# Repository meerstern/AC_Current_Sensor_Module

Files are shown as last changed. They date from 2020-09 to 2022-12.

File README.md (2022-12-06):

# AC電流センサ基板
Minimally invasive current sensor board

## 概要 
  * ホール素子を用いた商用交流用の電流センサ基板です  
  * 一般的なCT電流センサでは片方のみをクランプさせる必要があり、電源ケーブルの加工が必要です  
  * 一方、当センサは一般的な電源ケーブルを加工せずにそのまま近接させて使用します  
  * 機器のON、OFF状態の確認や大まかな電流変化の確認用途に最適です  
  * 電源ケーブルに近接させるだけで、電源ケーブルの電流に比例したアナログ電圧が出力されます  
  * 可変抵抗RV1で感度調整が可能です  
  * センサ電源は2.5V～5V電源を供給してください  
  
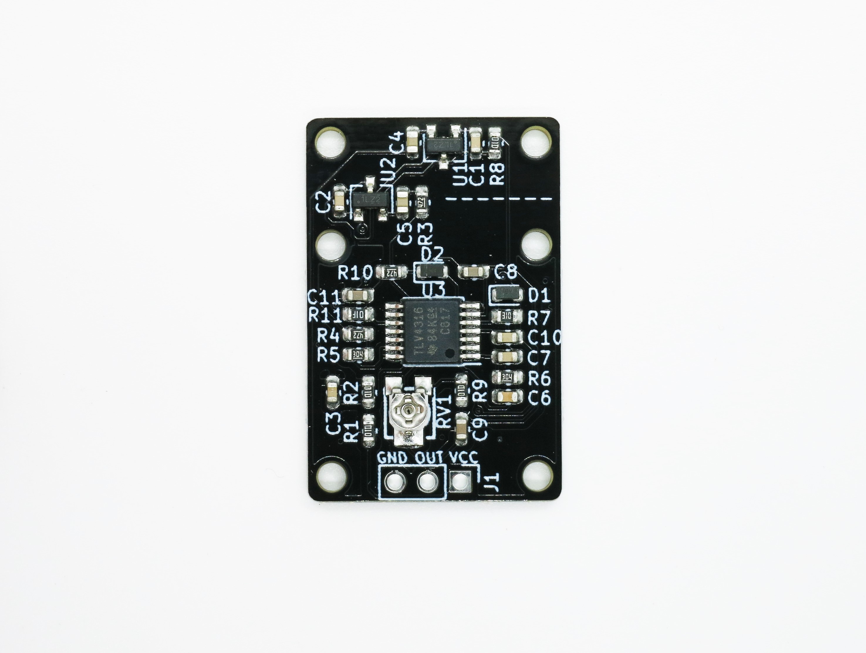
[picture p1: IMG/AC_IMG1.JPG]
   
   
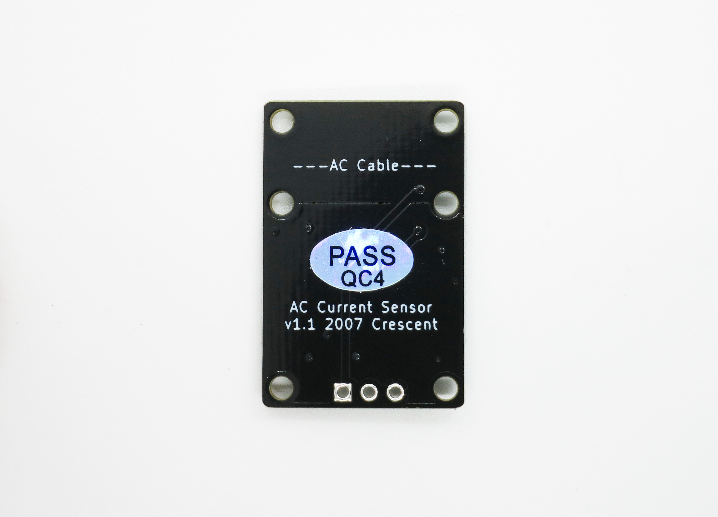
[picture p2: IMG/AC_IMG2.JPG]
   

## 使用方法
　* 小電流(数10W～数100W程度)の場合は部品側にシルクの点線に合わせて電源ケーブルを固定してください  
 
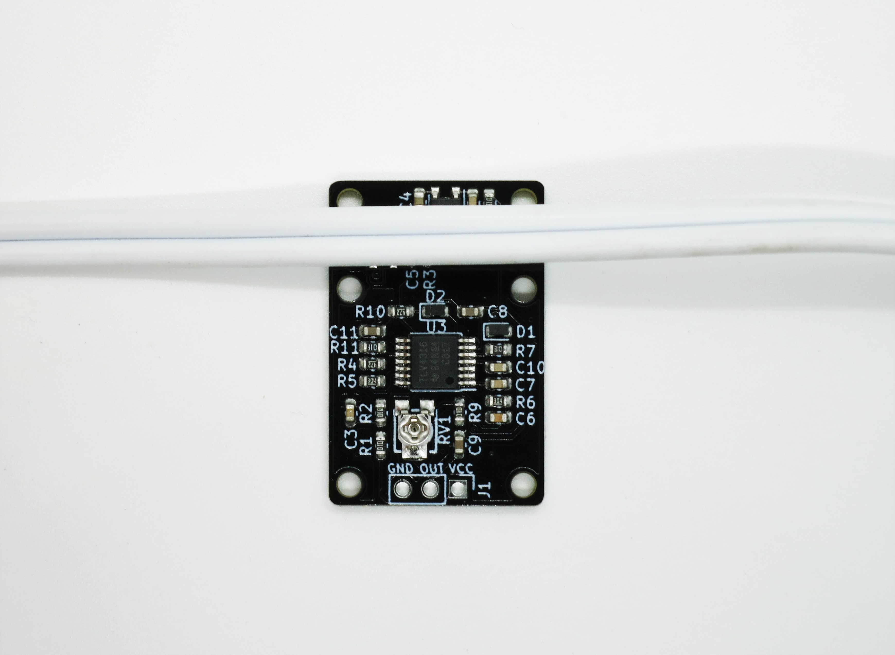
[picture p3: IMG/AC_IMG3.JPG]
 
　
  * 大電流(数100W～1000W程度)の場合は部品裏側のシルク点線に合わせて電源ケーブルを固定してください  
  
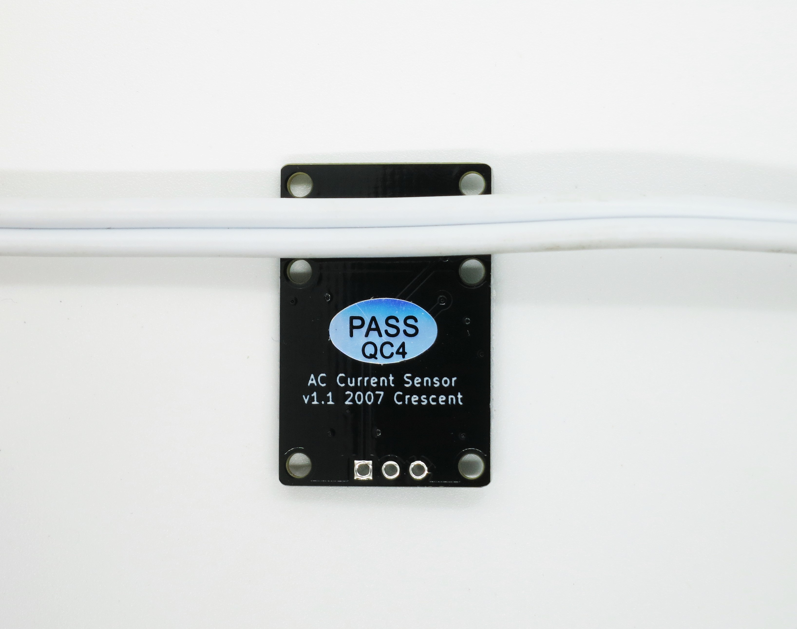
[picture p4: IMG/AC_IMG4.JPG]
 
 
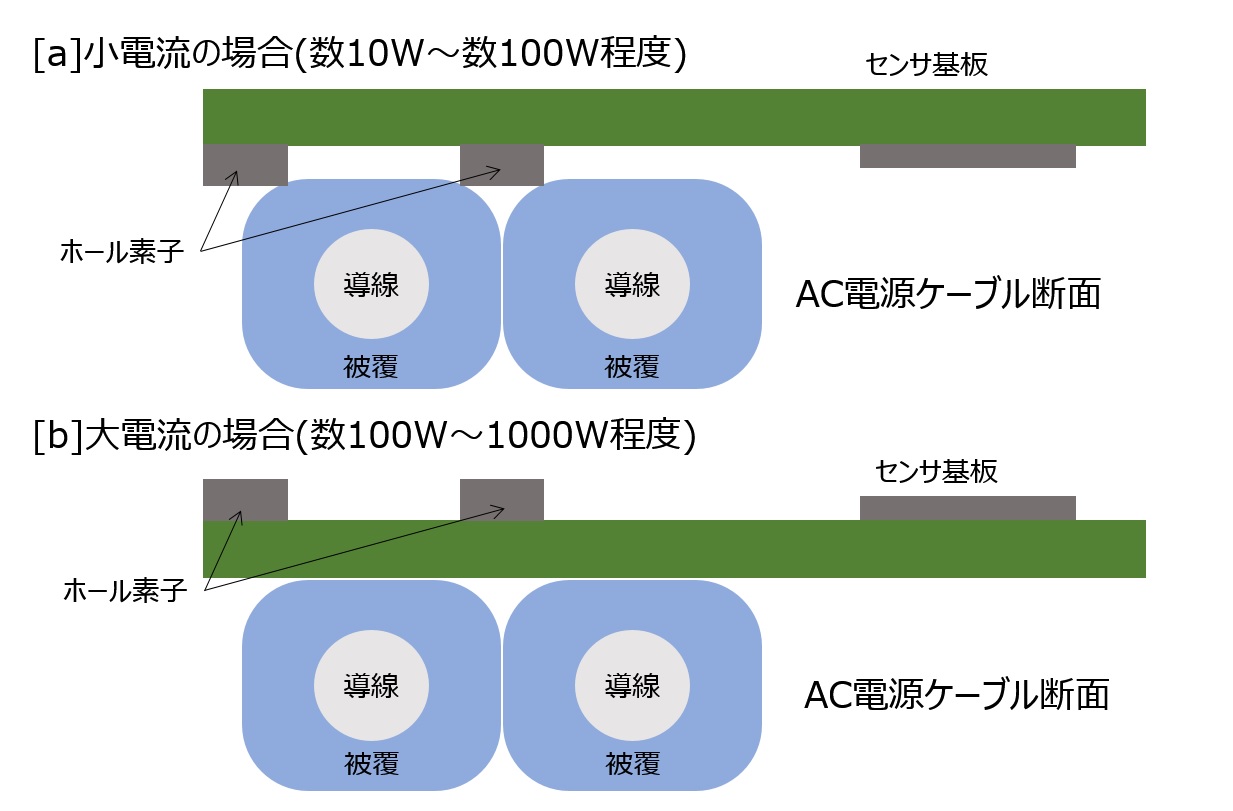
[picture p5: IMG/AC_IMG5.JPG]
 
 
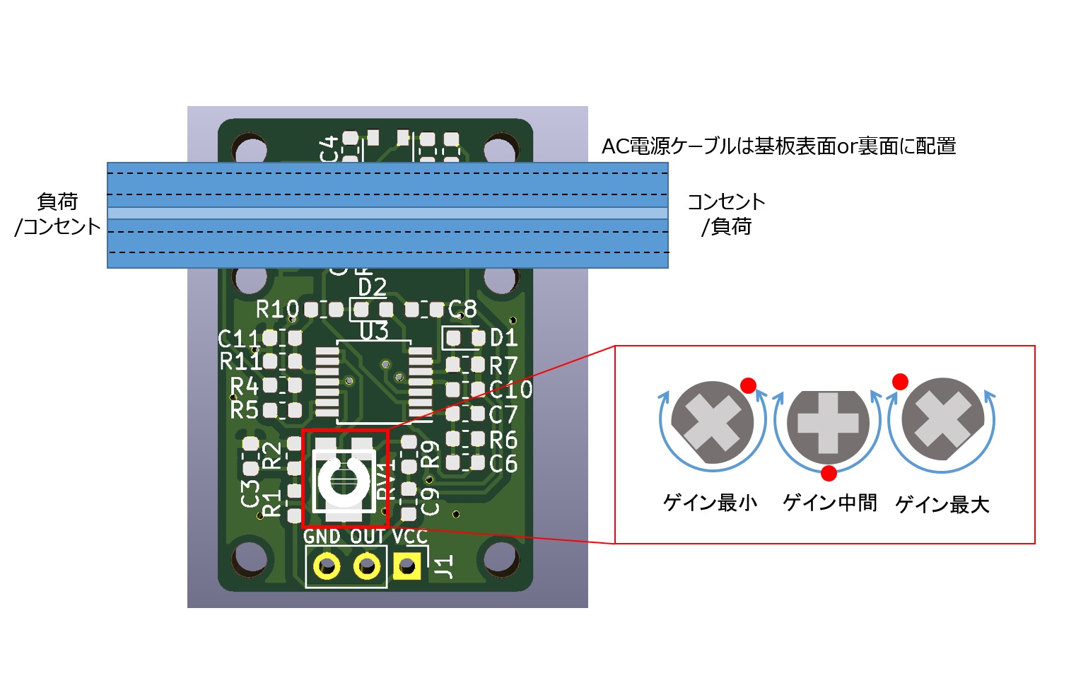
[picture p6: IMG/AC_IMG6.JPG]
 
 
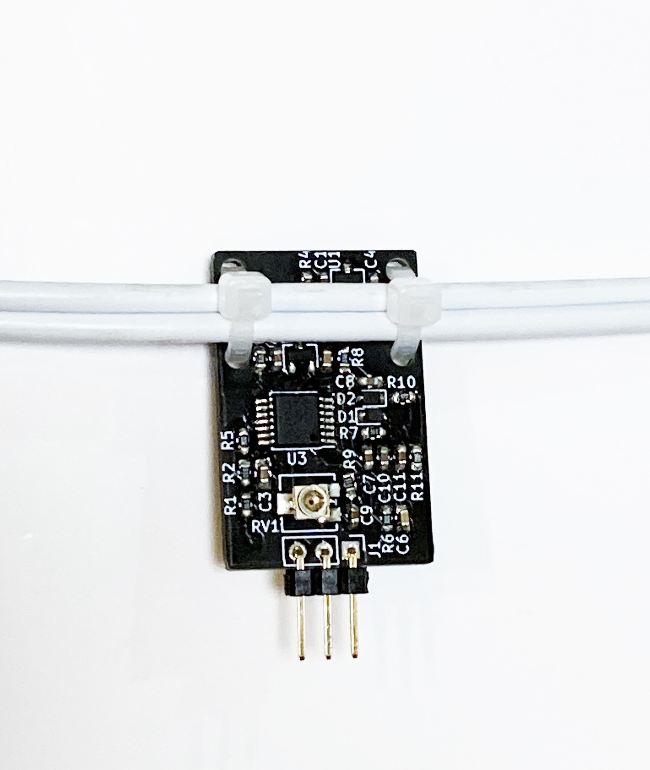
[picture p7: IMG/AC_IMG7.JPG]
 
    
## 注意 
 * 布巻き電源ケーブルや傷、破損のある電源ケーブルに対して使用しないでください  
 * 電源ケーブルの破損防止のため、電源ケーブルとセンサ基板を強く固定しないでください  
 * 当電流センサ基板は商用交流(50Hz、60Hz)専用で直流電流やその他交流電流の測定には使用できません  
 * 実験、評価用途を目的としています  
 * 15A以上の電流測定には使用しないでください  
 * 商用電源のノイズがアナログ出力に入る場合は必要に応じて、フィルタ処理をしてください  
 * 磁界変化をピークホールドさせるため、急激な電流変化や微小な電流変化の検出はできません  
 * 同じ電流であっても電源ケーブルの種類や取り付け位置によっても磁界の大きさが変化し、出力も合わせて変化します  
 * 電流とアナログ出力電圧の関係は事前にクランプ式電流センサ等で確認してください  
 * 負荷や使用する電源ケーブルによっては電流に対してアナログ出力が１次比例しない場合があります  
 * 電源ケーブルと電流センサ基板の取り付け位置を固定させて使用してください  
 * 当電流センサ基板上の部品を手で触れた状態では出力が不安定化する場合があります  
 * 可変抵抗RV1で感度によって異なりますが、電流0であってもオフセット電圧が0.2V~2V程度出力されます  
 * 当センサを使用したことによって発生した、いかなる損害については責任を負いかねます  
 
 ## 改版情報
 * v1.1→v1.2で出力リップル及び出力オフセット低減のため、変更しています(R9:100k→0ohm、C6:2nF→10nF)  
 * 基板レイアウトを一部変更していますが、回路に変更はありません  
 
 ## 販売サイト
  * [スイッチサイエンス][2]
  
  [2]: https://www.switch-science.com/products/6582
 
 MIT Lisense

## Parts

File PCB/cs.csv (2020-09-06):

ID | 参照記号 | パッケージ | 数 | 名称 | Supplier and ref
1 | REF4,REF6,REF5,REF3,REF4,REF1,REF2 | MountingHole_2.2mm_M2 | 7 | MountingHole_2.2mm_M2
2 | RV1 | rcl-RTRIMCVR42A | 1 | 1M
3 | C3,C10,C7,C2,C1 | C_0603_1608Metric | 5 | 0.1u
4 | U3 | TSSOP-14_4.4x5mm_P0.65mm | 1 | Opamp_Quad_Generic
5 | U2,U1 | SOT-23W | 2 | DRV5053EAQDBZR
6 | R11 | R_0603_1608Metric | 1 | 10M
7 | R10,R4,R3 | R_0603_1608Metric | 3 | 4.7k
8 | R9,R8,R2,R1 | R_0603_1608Metric | 4 | 100k
9 | R7 | R_0603_1608Metric | 1 | 1M
10 | R6,R5 | R_0603_1608Metric | 2 | 300k
11 | J1 | PinHeader_1x03_P2.54mm_Vertical | 1 | Conn_01x03
12 | D2,D1 | D_0603_1608Metric | 2 | D
13 | C11,C9,C8 | C_0603_1608Metric | 3 | 0.22u
14 | C6 | C_0603_1608Metric | 1 | 2n
15 | C5,C4 | C_0603_1608Metric | 2 | 1u

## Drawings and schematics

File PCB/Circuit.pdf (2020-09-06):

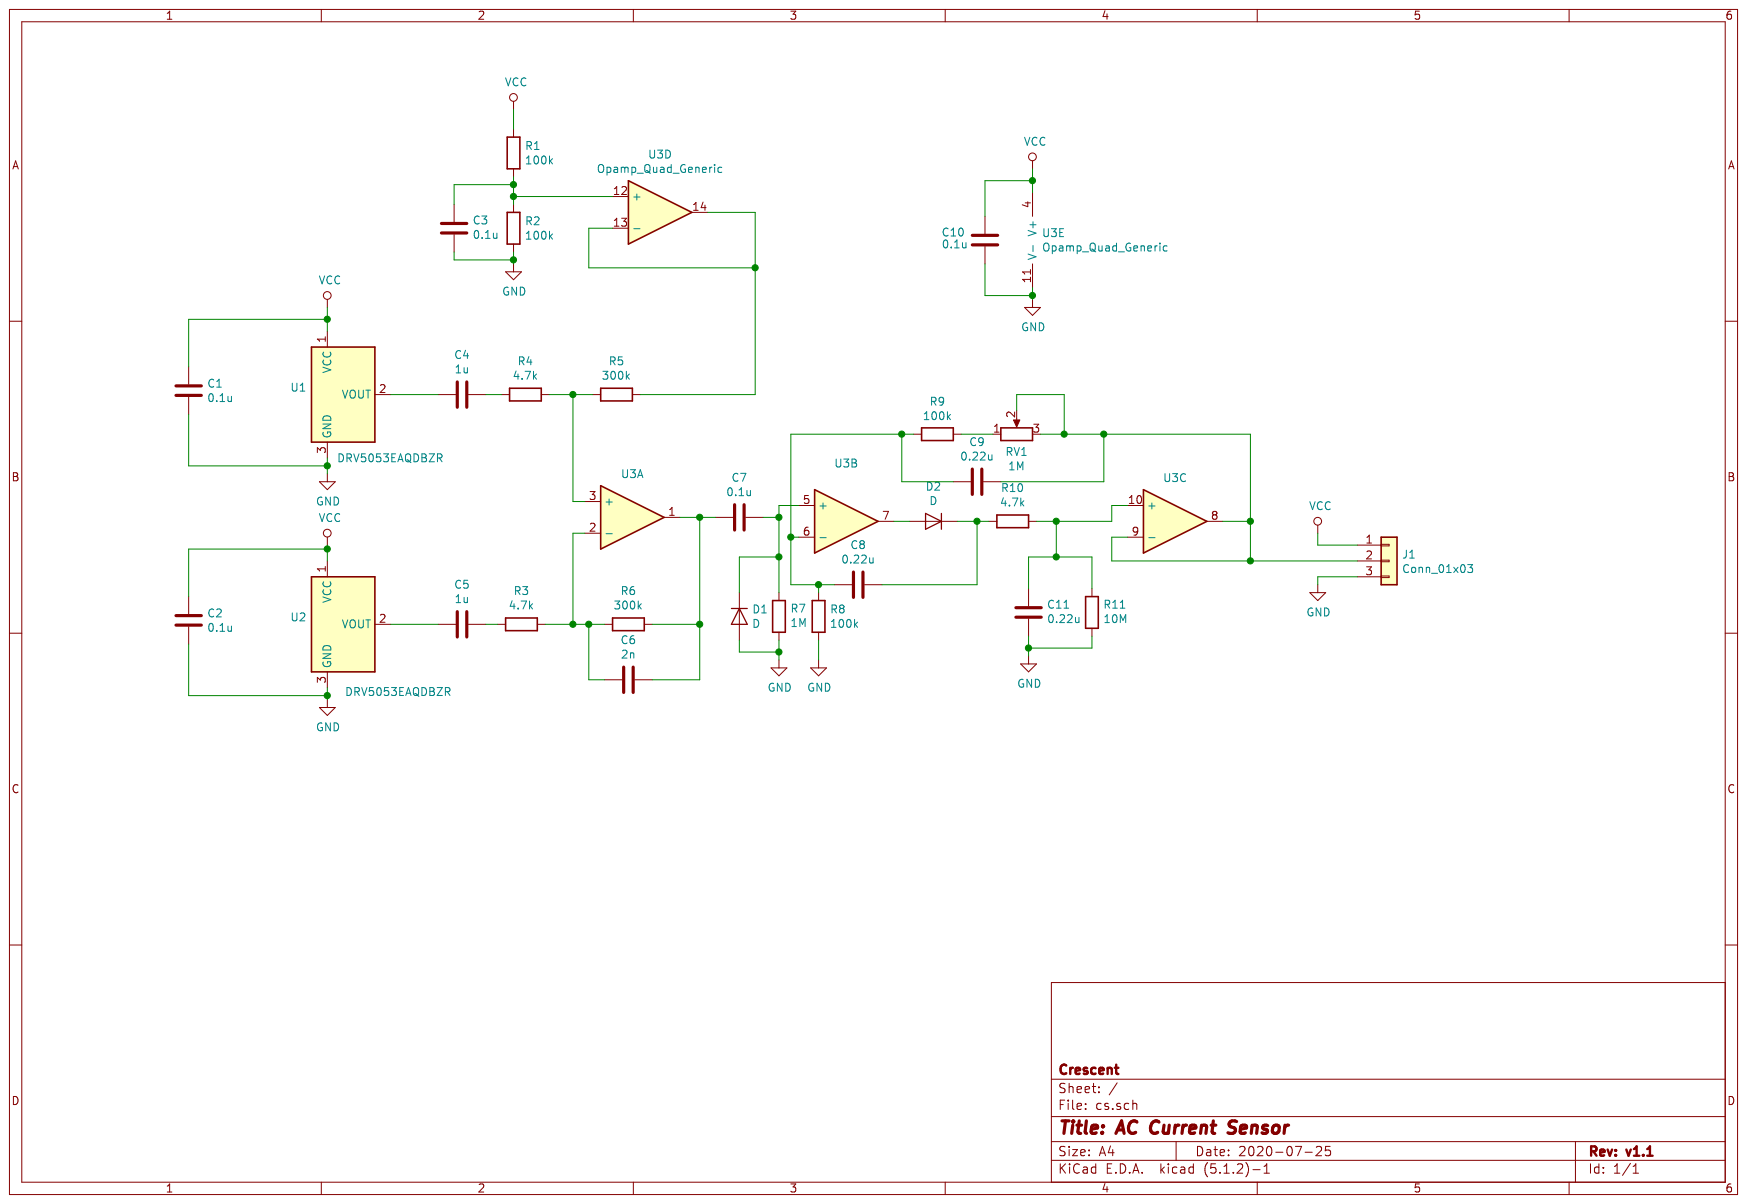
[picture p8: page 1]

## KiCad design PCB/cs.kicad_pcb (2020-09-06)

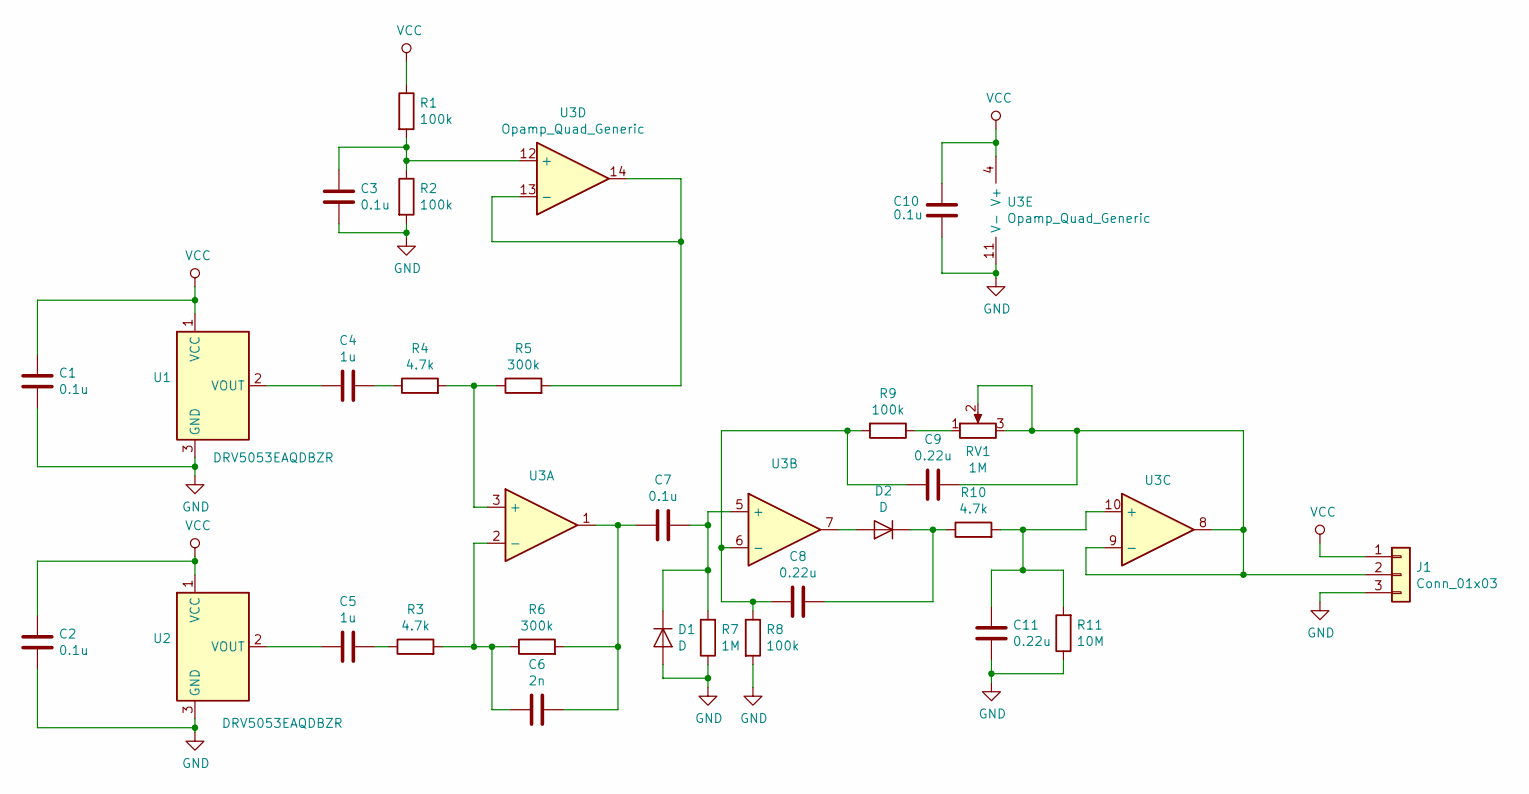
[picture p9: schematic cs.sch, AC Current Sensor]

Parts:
C1, C2, C3, C7, C10: 0.1u; C_0603_1608Metric
C4, C5: 1u; C_0603_1608Metric
C6: 2n; C_0603_1608Metric
C8, C9, C11: 0.22u; C_0603_1608Metric
D1, D2: D; D_0603_1608Metric
J1: Conn_01x03; PinHeader_1x03_P2.54mm_Vertical
R1, R2, R8, R9: 100k; R_0603_1608Metric
R3, R4, R10: 4.7k; R_0603_1608Metric
R5, R6: 300k; R_0603_1608Metric
R7: 1M; R_0603_1608Metric
R11: 10M; R_0603_1608Metric
RV1: 1M; rcl-RTRIMCVR42A
U1, U2: DRV5053EAQDBZR; SOT-23W
U3: Opamp_Quad_Generic; TSSOP-14_4.4x5mm_P0.65mm

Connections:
GND: C1.2, C2.2, C3.1, C10.2, C11.1, D1.2 (A), J1.3, R2.2, R7.1, R8.2, R11.1, U1.3 (GND), U2.3 (GND), U3.11 (V-)
unnamed: C3.2, R1.2, R2.1, U3.12 (+)
unnamed: C4.1, R4.1
unnamed: C4.2, U1.2 (VOUT)
unnamed: C5.1, R3.1
unnamed: C5.2, U2.2 (VOUT)
unnamed: C6.1, C7.2, R6.2, U3.1
unnamed: C6.2, R3.2, R6.1, U3.2 (-)
unnamed: C7.1, D1.1 (K), R7.2, U3.5 (+)
unnamed: C8.1, D2.1 (K), R10.1
unnamed: C8.2, C9.2, R8.1, R9.2, U3.6 (-)
unnamed: C9.1, J1.2, RV1.2, RV1.3, U3.8, U3.9 (-)
unnamed: C11.2, R10.2, R11.2, U3.10 (+)
unnamed: D2.2 (A), U3.7
unnamed: R4.2, R5.1, U3.3 (+)
unnamed: R5.2, U3.13 (-), U3.14
unnamed: R9.1, RV1.1
VCC: C1.1, C2.1, C10.1, J1.1, R1.1, U1.1 (VCC), U2.1 (VCC), U3.4 (V+)

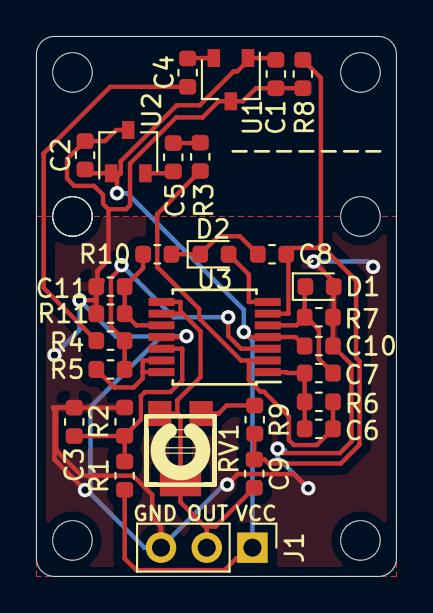
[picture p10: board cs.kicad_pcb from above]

Board: 2 copper layers, 20.0 x 30.0 mm, 36 parts (0 on the bottom side), 18 nets.

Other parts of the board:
REF1, REF2, REF3, REF4, REF4#2, REF5, REF6: MountingHole_2.2mm_M2
